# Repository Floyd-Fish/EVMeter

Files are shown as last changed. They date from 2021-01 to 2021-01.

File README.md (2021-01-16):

# Overview
An EV(Exposure Value) Meter measures EV parameters for cameras automatically. Also measures the Color Temperature.Designed to simplify MF controls on Digital or Mechanical DSLRs

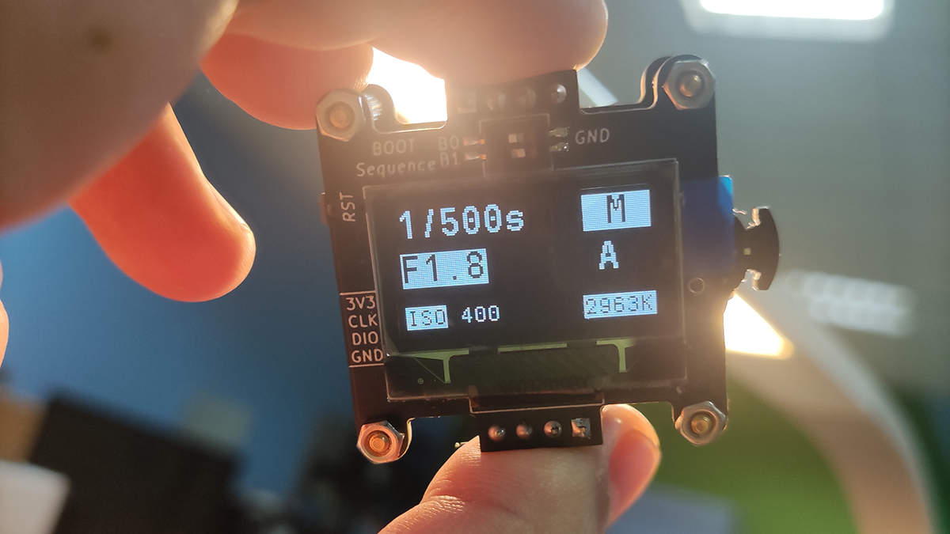
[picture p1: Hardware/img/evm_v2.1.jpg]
evm_v2.1

## Progress

V2.1 has been updated: Basic functions completed, **but bug exists**.  

## Hardware design
Tools: KiCad  
See dir: Hardware/Kicad_project

## Software design

**History Version**

- V1.0
  - Tools: Clion + STM32CubeMx  
  - MCU: STM32F070F6P6  
  - See dir: Software

- V2.0
  - Tools: Clion + STM32CubeMx
  - MCU: STM32F072CBT6
  - See dir: Software

- V2.1
  - Tools: MDK5 + STM32CubeMx
  - MCU: STM32F072CBT6
  - See dir: Software

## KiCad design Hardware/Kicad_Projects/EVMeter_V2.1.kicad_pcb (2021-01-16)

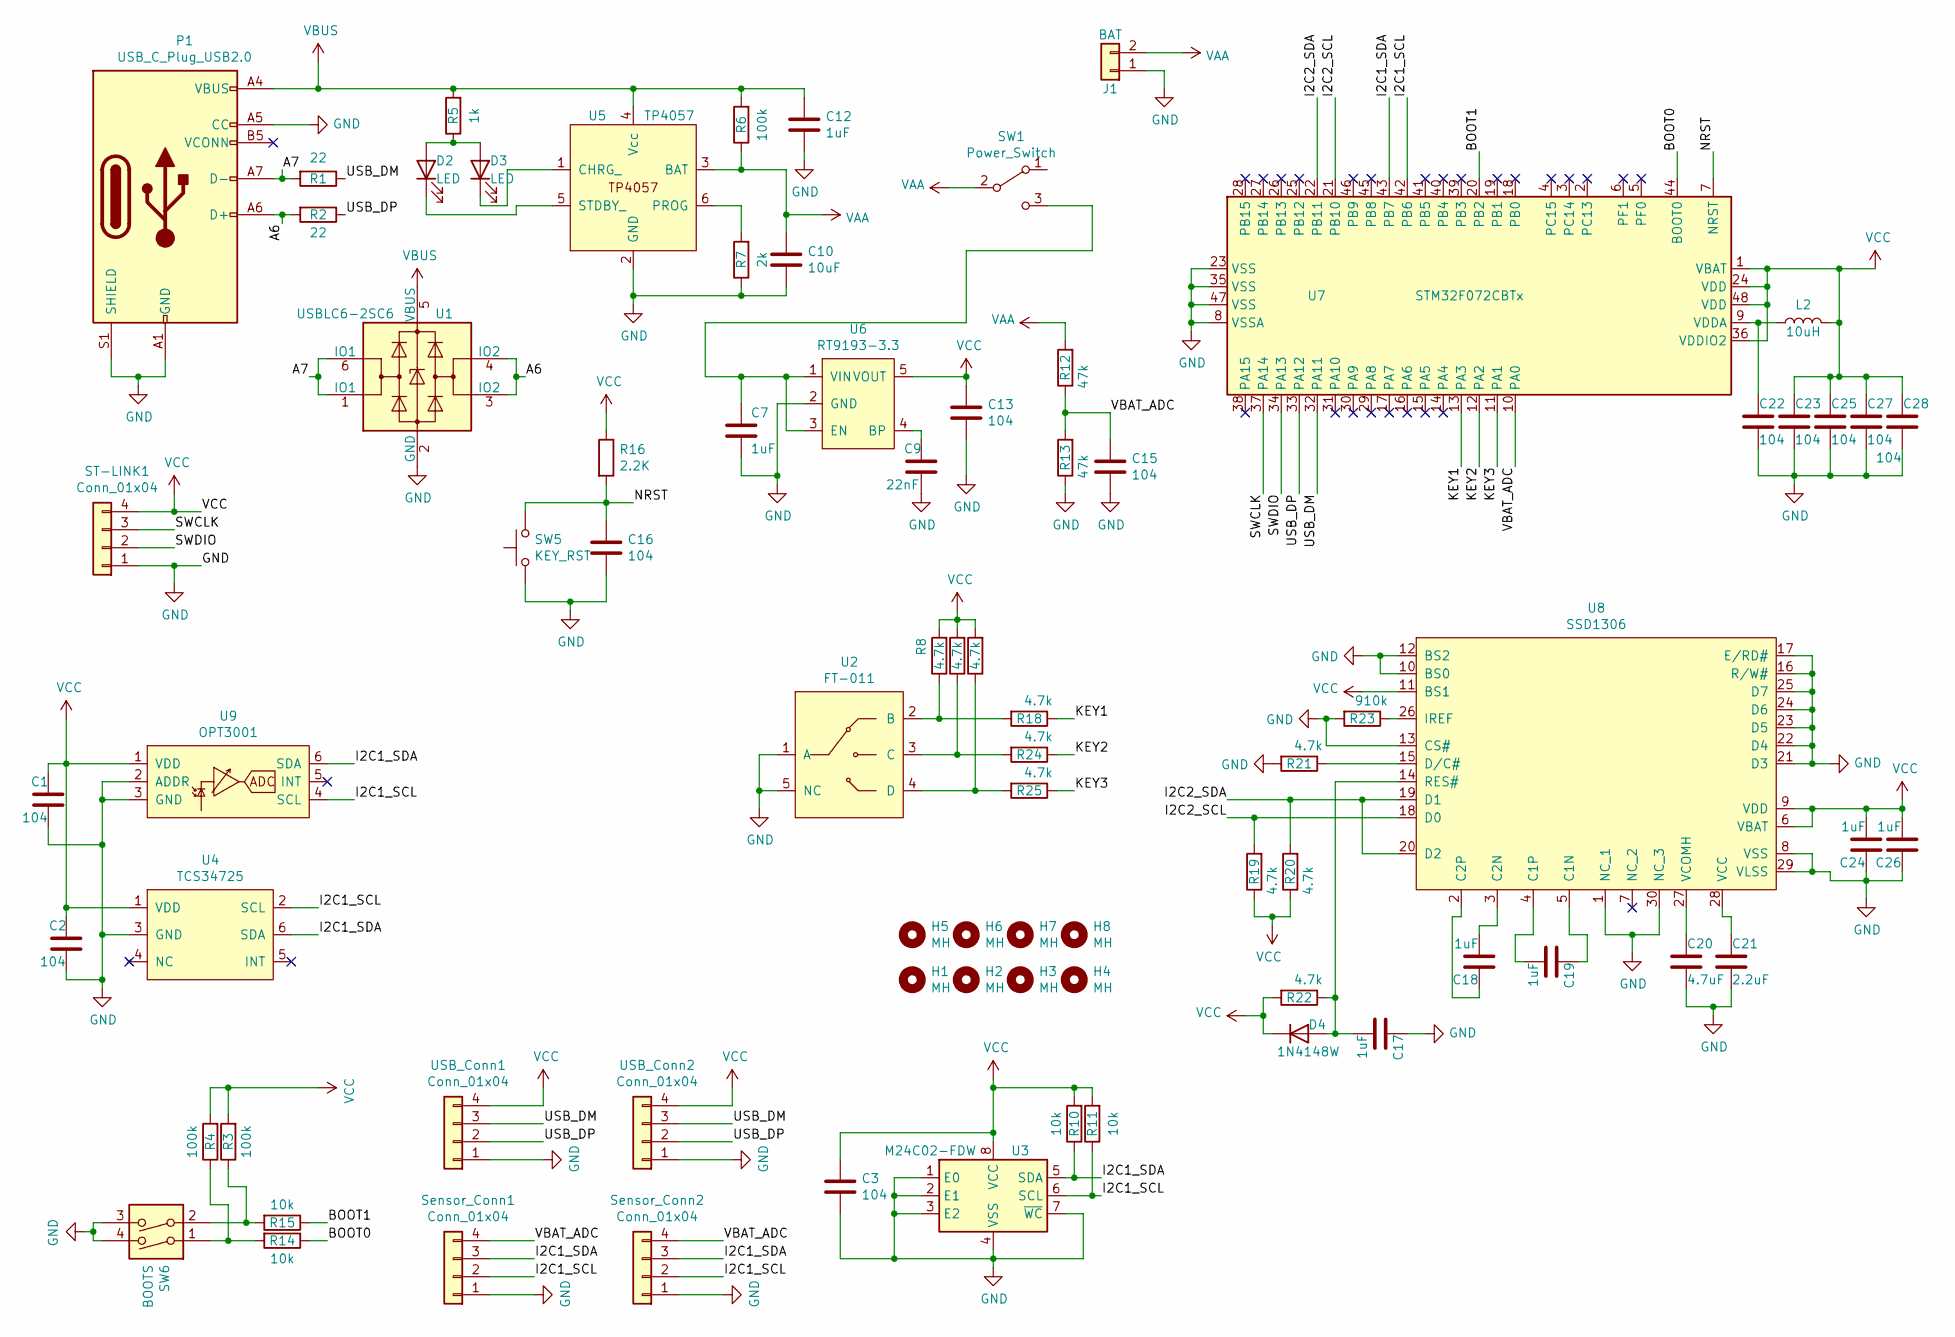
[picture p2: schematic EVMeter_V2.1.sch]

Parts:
C1, C2, C3, C13, C15, C16, C22, C23, C25, C27, C28: 104; C_0603_1608Metric
C7, C12, C17, C18, C19, C24, C26: 1uF; C_0603_1608Metric
C9: 22nF; C_0603_1608Metric
C10: 10uF; C_0805_2012Metric
C20: 4.7uF; C_0805_2012Metric
C21: 2.2uF; C_0805_2012Metric
D2, D3: LED; LED_0603_1608Metric_Castellated
D4: 1N4148W; D_SOD-323
H1, H2, H3, H4, H5, H6, H7, H8: MH; MountingHole_2.2mm_M2
J1: BAT; PinSocket_1x02_P2.00mm_Vertical
L2: 10uH; L_0805_2012Metric_Pad1.15x1.40mm_HandSolder
P1: USB_C_Plug_USB2.0; USB_C_Receptacle_HRO_TYPE-C-31-M-12
R1, R2: 22; R_0603_1608Metric
R3, R4, R6: 100k; R_0603_1608Metric
R5: 1k; R_0603_1608Metric
R7: 2k; R_0603_1608Metric
R8, R9, R17, R18, R19, R20, R21, R22, R24, R25: 4.7k; R_0603_1608Metric
R10, R11, R14, R15: 10k; R_0603_1608Metric
R12, R13: 47k; R_0603_1608Metric
R16: 2.2K; R_0603_1608Metric
R23: 910k; R_0603_1608Metric
ST-LINK1: Conn_01x04; Molex_PicoBlade_53261-0471_1x04-1MP_P1.25mm_Horizontal
SW1: Power_Switch; SW_SPDT_CK-JS102011SAQN
SW5: KEY_RST; Panasonic_EVQPUL_EVQPUC
SW6: BOOTS; SW_DIP_SPSTx02_Slide_Yourcee_W5.40mm_P1.27mm
Sensor_Conn1: Conn_01x04; PinHeader_1x04_P2.54mm_Vertical
Sensor_Conn2: Conn_01x04; PinSocket_1x04_P2.54mm_Vertical
U1: USBLC6-2SC6; SOT-23-6
U2: FT-011
U3: M24C02-FDW; SOIC-8_3.9x4.9mm_P1.27mm
U4: TCS34725; TSL2591_DFN6
U5: TP4057; SOT-23-6
U6: RT9193-3.3; SOT-23-5
U7: STM32F072CBTx; LQFP-48_7x7mm_P0.5mm
U8: SSD1306; SSD1306-12864_Alter
U9: OPT3001; USON-6
USB_Conn1: Conn_01x04; PinHeader_1x04_P2.54mm_Vertical
USB_Conn2: Conn_01x04; PinSocket_1x04_P2.54mm_Vertical

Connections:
/A6: P1.A6 (D+), R2.2, U1.3 (IO2), U1.4 (IO2)
/A7: P1.A7 (D-), R1.2, U1.1 (IO1), U1.6 (IO1)
/BOOT0: R14.1, U7.44 (BOOT0)
/BOOT1: R15.1, U7.20 (PB2)
/I2C1_SCL: R11.1, Sensor_Conn1.2, Sensor_Conn2.2, U3.6 (SCL), U4.2 (SCL), U7.42 (PB6), U9.4 (SCL)
/I2C1_SDA: R10.1, Sensor_Conn1.3, Sensor_Conn2.3, U3.5 (SDA), U4.6 (SDA), U7.43 (PB7), U9.6 (SDA)
/I2C2_SCL: R19.2, U7.21 (PB10), U8.18 (D0)
/I2C2_SDA: R20.2, U7.22 (PB11), U8.19 (D1), U8.20 (D2)
/KEY1: R18.1, U7.13 (PA3)
/KEY2: R24.1, U7.12 (PA2)
/KEY3: R25.1, U7.11 (PA1)
/NRST: C16.1, R16.2, SW5.2, U7.7 (NRST)
/SWCLK: ST-LINK1.3, U7.37 (PA14)
/SWDIO: ST-LINK1.2, U7.34 (PA13)
/USB_DM: R1.1, U7.32 (PA11), USB_Conn1.3, USB_Conn2.3
/USB_DP: R2.1, U7.33 (PA12), USB_Conn1.2, USB_Conn2.2
/VBAT_ADC: C15.1, R12.1, R13.2, Sensor_Conn1.4, Sensor_Conn2.4, U7.10 (PA0)
GND: C1.2, C2.2, C3.2, C7.2, C9.2, C10.2, C12.2, C13.2, C15.2, C16.2, C17.1, C20.2, C21.2, C22.2, C23.2, C24.1, C25.2, C26.1, C27.2, C28.2, J1.1, P1.A1 (GND), P1.A5 (CC), P1.A12 (GND), P1.B1 (GND), P1.B12 (GND), P1.S1 (SHIELD), R7.1, R13.1, R21.2, R23.2, ST-LINK1.1, SW5.1, SW6.3, SW6.4, Sensor_Conn1.1, Sensor_Conn2.1, U1.2 (GND), U2.1 (A), U2.5 (NC), U3.1 (E0), U3.2 (E1), U3.3 (E2), U3.4 (VSS), U3.7 (~WC), U4.3 (GND), U5.2 (GND), U6.2 (GND), U7.8 (VSSA), U7.23 (VSS), U7.35 (VSS), U7.47 (VSS), U8.1 (NC_1), U8.8 (VSS), U8.10 (BS0), U8.12 (BS2), U8.13 (CS#), U8.16 (R/W#), U8.17 (E/RD#), U8.21 (D3), U8.22 (D4), U8.23 (D5), U8.24 (D6), U8.25 (D7), U8.29 (VLSS), U8.30 (NC_3), U9.2 (ADDR), U9.3 (GND), USB_Conn1.1, USB_Conn2.1
unnamed: C7.1, SW1.3 (C), U6.1 (VIN), U6.3 (EN)
unnamed: C9.1, U6.4 (BP)
unnamed: C17.2, D4.2 (A), R22.1, U8.14 (RES#)
unnamed: C18.1, U8.2 (C2P)
unnamed: C18.2, U8.3 (C2N)
unnamed: C19.1, U8.5 (C1N)
unnamed: C19.2, U8.4 (C1P)
unnamed: C20.1, U8.27 (VCOMH)
unnamed: C21.1, U8.28 (VCC)
unnamed: C22.1, L2.1, U7.9 (VDDA)
unnamed: D2.1 (K), U5.5 (STDBY_)
unnamed: D2.2 (A), D3.2 (A), R5.1
unnamed: D3.1 (K), U5.1 (CHRG_)
unnamed: R7.2, U5.6 (PROG)
unnamed: R4.1, R14.2, SW6.1
unnamed: R3.1, R15.2, SW6.2
unnamed: R17.1, R25.2, U2.4 (D)
unnamed: R8.1, R18.2, U2.2 (B)
unnamed: R21.1, U8.15 (D/C#)
unnamed: R23.1, U8.26 (IREF)
unnamed: R9.1, R24.2, U2.3 (C)
VAA: C10.1, J1.2, R6.1, R12.2, SW1.2 (B), U5.3 (BAT)
VBUS: C12.1, P1.A4 (VBUS), P1.A9 (VBUS), P1.B4 (VBUS), P1.B9 (VBUS), R5.2, R6.2, U1.5 (VBUS), U5.4 (Vcc)
VCC: C1.1, C2.1, C3.1, C13.1, C23.1, C24.2, C25.1, C26.2, C27.1, C28.1, D4.1 (K), L2.2, R3.2, R4.2, R8.2, R9.2, R10.2, R11.2, R16.1, R17.2, R19.1, R20.1, R22.2, ST-LINK1.4, U3.8 (VCC), U4.1 (VDD), U6.5 (VOUT), U7.1 (VBAT), U7.24 (VDD), U7.36 (VDDIO2), U7.48 (VDD), U8.6 (VBAT), U8.9 (VDD), U8.11 (BS1), U9.1 (VDD), USB_Conn1.4, USB_Conn2.4

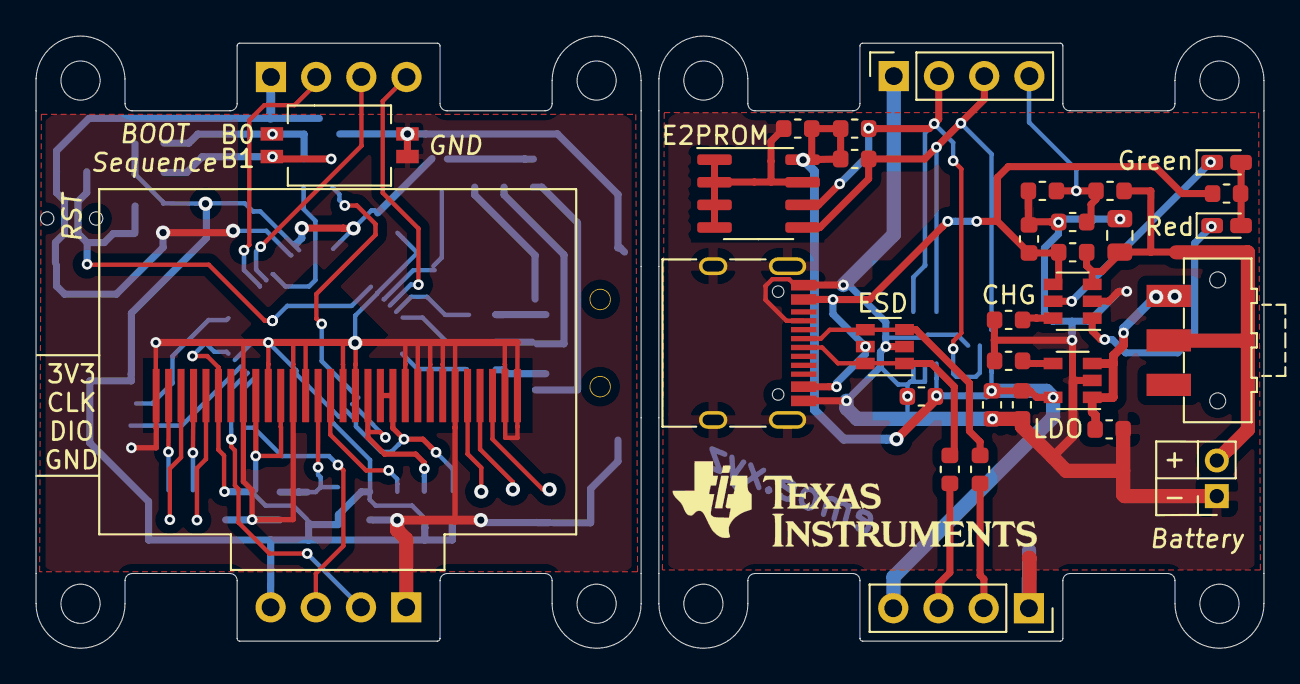
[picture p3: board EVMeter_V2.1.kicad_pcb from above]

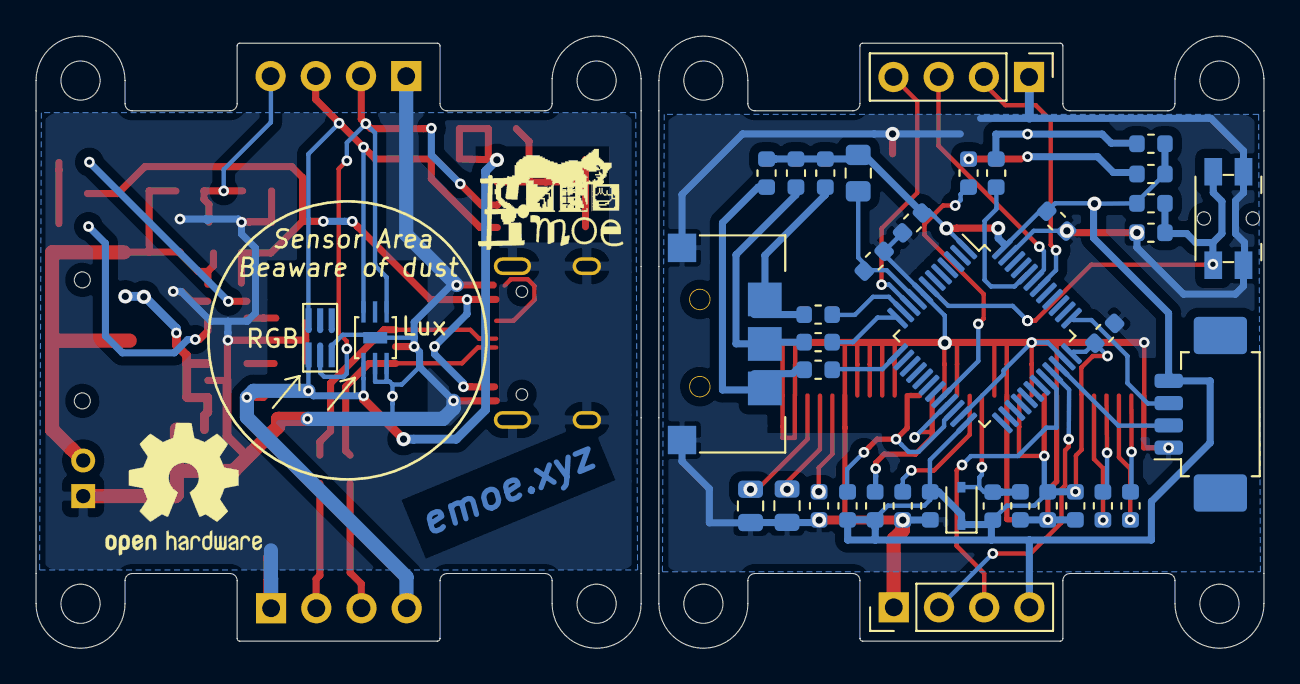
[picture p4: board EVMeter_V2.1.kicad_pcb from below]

Board: 2 copper layers, 69.0 x 34.4 mm, 78 parts (39 on the bottom side), 42 nets.

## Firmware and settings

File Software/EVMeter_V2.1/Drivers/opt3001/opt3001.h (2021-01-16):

#ifndef __OPT3001_H
#define __OPT3001_H

#include "main.h"

/* HAL I2C Config */
extern I2C_HandleTypeDef    hi2c1;
#define OPT3001_I2C_PORT    &hi2c1

/*  Address Select   |   Hardware connection
 *     0x44 << 1     |       ADDR to GND
 *     0x45 << 1     |       ADDR to VCC
 *     0x46 << 1     |       ADDR to SDA
 *     0x47 << 1     |       ADDR to SCL
 */   
#define OPT3001_ADDR            		(0x44<<1)

/* Register MAP */
#define OPT3001_RESULT_REG              0x00
#define OPT3001_CONFIG_REG              0x01
#define OPT3001_LOWLIMIT_REG            0x02
#define OPT3001_HIGHLIMIT_REG           0x03
#define OPT3001_MANUFACTUREID_REG       0x7E
#define OPT3001_DEVICEID_REG            0x7F

/* Conversion Time Params */
#define DEFAULT_CONFIG_800              0b1100110000010000 // 800ms
#define DEFAULT_CONFIG_800_OS           0b1100101000010000 // 800ms, one shot
#define DEFAULT_CONFIG_100              0b1100010000010000 // 100ms
#define DEFAULT_CONFIG_100_OS           0b1100001000010000 // 100ms, one shot

#define DEFAULT_CONFIG_SHDWN            0xC810 // Shut down converter

/* 	CONFIG REGISTER BITS:| RN3 RN2 RN1 RN0 | CT M1 M0 OVF | CRF FH FL L | Pol ME FC1 FC0 |
	RN3 to RN0 = Range select:
                    1100 by default, enables auto-range 
	CT = Conversion time bit
                    0 = 100ms conversion time
                    1 = 800ms conversion time (default)
	M1 to M0 = Mode bits
                    00 = Shutdown mode
                    01 = Single shot mode
                    10 = Continuous conversion (default)
                    11 = Continuous conversion
	OVF (Bit 8)     Overflow flag. When set the conversion result is overflown.
	CRF (Bit 7)     Conversion ready flag. Sets at end of conversion. Clears by read or write of the Configuration register.
	FH (Bit 6)      Flag high bit. Read only. Sets when result is higher that TH register. Clears when Config register is 
					read or when Latch bit is 0 and the result goes bellow TH register.
	FL (Bit 5)      Flag low bit. Read only. Sets when result is lower that TL register. Clears when Config register is read 
                    or when Latch bit is 0 and the result goes above TL register.
	L (Bit 4)       Latch bit. Read/write bit. Default 1, Controls Latch/transparent functionality of FH and FL bits. When 
                    L = 1 the Alert pin works in window comparator mode with Latched functionality When L = 0 the Alert pin 
                    works in transparent mode and the two limit registers provide the hysteresis.
	Pol (Bit 3)     Polarity. Read/write bit. Default 0, Controls the active state of the Alert pin. Pol = 0 means Alert 
                    active low.
	ME (Bit 2)      Exponent mask. In fixed range modes masks the exponent bits in the result register to 0000.
	FC1 to FC0  -   Fault count bits. Read/write bits. Default 00 - the first fault will trigger the alert pin.
*/

#define OPT3001_CFG_FL          (1 << 5)
#define OPT3001_CFG_FH          (1 << 6)
#define OPT3001_CFG_CRF         (1 << 7)
#define OPT3001_CFG_OVF         (1 << 8)
#define OPT3001_CFG_L           (1 << 4)
#define OPT3001_CFG_POL         (1 << 3)
#define OPT3001_CFG_ME          (1 << 2)
#define OPT3001_CFG_CT          (1 << 11)
#define OPT3001_CFG_FC_SHIFT    0
#define OPT3001_CFG_FC_MASK     (0x03 << OPT3001_CFG_FC_SHIFT)
#define OPT3001_CFG_M_SHIFT     9
#define OPT3001_CFG_M_MASK      (0x03 << OPT3001_CFG_M_SHIFT)
#define OPT3001_CFG_RN_SHIFT    12
#define OPT3001_CFG_RN_MASK     (0xf << OPT3001_CFG_RN_SHIFT)

/* Functions */

void OPT3001_WriteData(uint8_t addr, uint16_t data);

uint16_t OPT3001_ReadData(void);

uint8_t OPT3001_Init(void);

float OPT3001_CalcLux(void);

uint16_t OPT3001_ReadID(void);

uint16_t OPT3001_ReadManu_ID(void);

#endif

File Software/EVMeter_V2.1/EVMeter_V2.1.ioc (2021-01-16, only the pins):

Mcu.UserName=STM32F072CBTx
PA0.Signal=ADC_IN0
PA1.Signal=GPIO_Input
PA11.Signal=USB_DM
PA12.Signal=USB_DP
PA13.Signal=SYS_SWDIO
PA14.Signal=SYS_SWCLK
PA2.Signal=GPIO_Input
PA3.Signal=GPIO_Input
PB10.Signal=I2C2_SCL
PB11.Signal=I2C2_SDA
PB6.Signal=I2C1_SCL
PB7.Signal=I2C1_SDA
PB9.Signal=GPIO_Output

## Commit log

2020-03-17 Add initial project frameworks
    [EV Meter.kicad_pcb, EV Meter.sch]
2020-03-24 Update PCB gerber
    [EV Meter-B_Cu.gbr, EV Meter-B_Mask.gbr, EV Meter-B_Paste.gbr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]
2020-06-18 Update Version V2.0's Hardware design
    [EV Meter-B_Cu.gbr, EV Meter-B_Mask.gbr, EV Meter-B_Paste.gbr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]
2021-01-16 Update V2.1 Design
    [EVMeter_V2.0-B_Cu.gbr, EVMeter_V2.0-B_Mask.gbr, EVMeter_V2.0-B_Paste.gbr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]
